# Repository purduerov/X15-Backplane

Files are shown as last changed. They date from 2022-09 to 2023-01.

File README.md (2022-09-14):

# Readme for X15-Backplane

Whenever you make a new part, download the datasheet and save it here _**and**_ with the part in the parts library

Always pull other people's changes before beginning to work
`git pull`

Be sure to push your changes after  working on them. Run:
1. `git add .` to add any files in this directory or a subdirectory
or `git add -u` to add any modified files
2. (Optional) `git clean -nX` to see what ignored files can be removed
	`git clean -fX` removes ignored files (Eagle backups)
3. `git commit -m "helpful commit message"` with a description of the work that you did
4. `git push` to push your work to github

Other helpful commands
* `git status` says information about modified and staged files
* `git log` shows the recent commits of the repository
* `git log filename.extension` show the recent commits for just that file
* `git checkout first-couple-letter-of-commit-id` lets you go back to a previous version
* `git checkout master` brings you back to the latest commit
* `git tag` lists the tags
* `git tag -a orderX -m "the version of the board placed for the X'th order"` tag a specific commit
* `git push --tags` needed to push tags to remote
* `git show orderX` show the commit log for the given tag
* `git checkout orderX` go back and interact with the files at the tagged commit

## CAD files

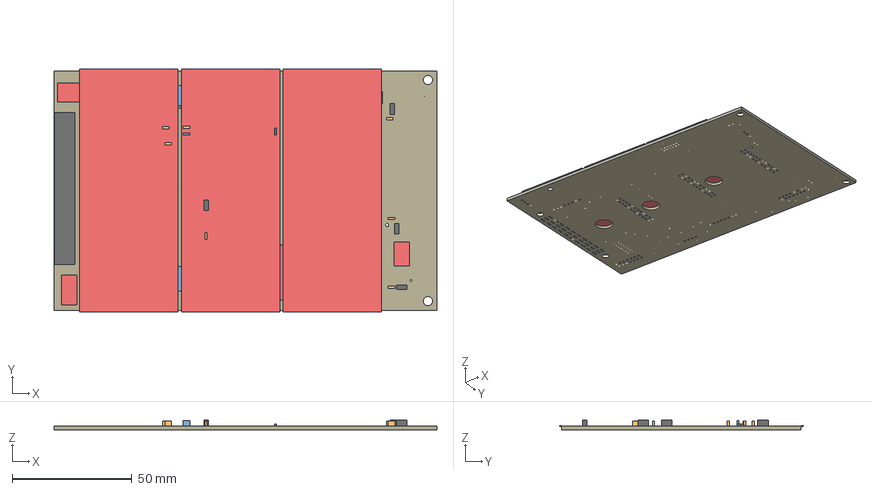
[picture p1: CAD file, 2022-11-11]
X15-Backplane.step
160.0 x 101.6 x 4.16 mm
Board
0.1uF
330uF x 8
PXC-PTSM-04-RA-1778641
0.5A/40V/420mV
MPPT-10-01-01-L-RA-SD
6-32-HOLE x 2
PXC-8-RA-1778683 x 2
BACKPLANE_ESC_ADAPTER_PWRBKP x 3
DISCRETECOMPONENTS_SW_2512
BACKPLANE-DISTRIBUTION
BACKPLANE->DATACONV
BACKPLANE_CONNECTORSBKP
LED_3MM x 4
8X_CONN
IPL1-103-01-L-S-K
IPL1-104-01-X-S-K

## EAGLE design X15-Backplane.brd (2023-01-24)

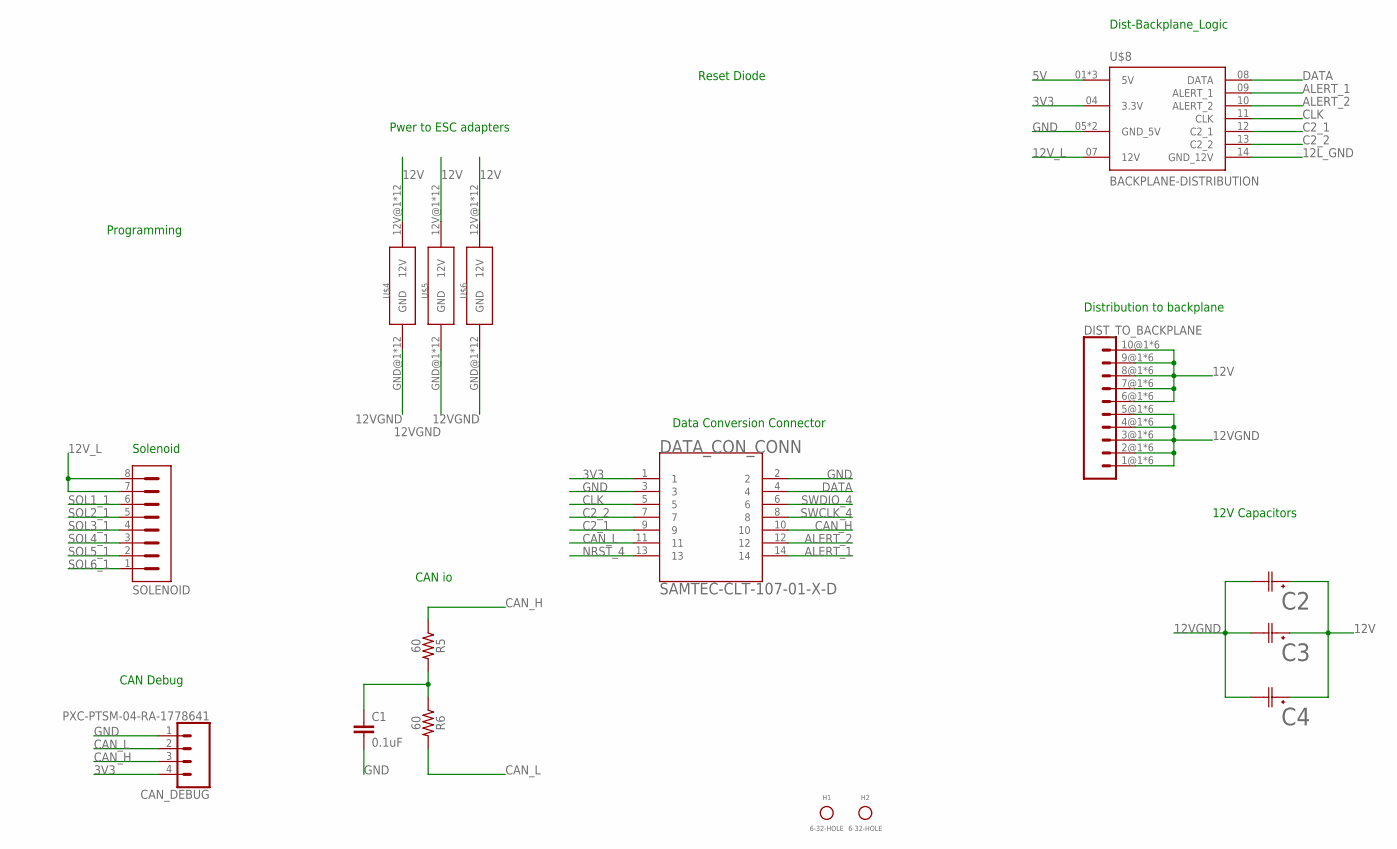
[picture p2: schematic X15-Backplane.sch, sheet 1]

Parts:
C1: 0.1uF; 0603
C2, C3, C4: UCV1E561MNL1GSCAP_UCD_8X10_NCH; CAP_UCD_8X10_NCH
CAN_DEBUG: PXC-PTSM-04-RA-1778641
DATA_CON_CONN: BACKPLANE->DATACONV; SAMTEC-CLT-107-01-X-D-BACKPLANE
DIST_TO_BACKPLANE: MPPT-10-01-01-L-RA-SD
H1, H2: 6-32-HOLE
R5, R6: 60; 0603
SOLENOID: PXC-8-RA-1778683
U$4, U$5, U$6: BACKPLANE_ESC_ADAPTER_PWRBKP; BACKPLANE_ESC_ADAPTER_BKP_PWR
U$8: BACKPLANE-DISTRIBUTION; SAMTEC_IPL1-107-01-X-D-K(B-D)

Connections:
3V3: CAN_DEBUG.4, DATA_CON_CONN.1, U$8.04 (3.3V); also elsewhere on the board
5V: U$8.01 (5V), U$8.02 (5V), U$8.03 (5V); also elsewhere on the board
12L_GND: U$8.14 (GND_12V); also elsewhere on the board
12V: C2.1, C3.1, C4.1, DIST_TO_BACKPLANE.6@1 (6), DIST_TO_BACKPLANE.6@2 (6), DIST_TO_BACKPLANE.6@3 (6), DIST_TO_BACKPLANE.6@4 (6), DIST_TO_BACKPLANE.6@5 (6), DIST_TO_BACKPLANE.6@6 (6), DIST_TO_BACKPLANE.7@1 (7), DIST_TO_BACKPLANE.7@2 (7), DIST_TO_BACKPLANE.7@3 (7), DIST_TO_BACKPLANE.7@4 (7), DIST_TO_BACKPLANE.7@5 (7), DIST_TO_BACKPLANE.7@6 (7), DIST_TO_BACKPLANE.8@1 (8), DIST_TO_BACKPLANE.8@2 (8), DIST_TO_BACKPLANE.8@3 (8), DIST_TO_BACKPLANE.8@4 (8), DIST_TO_BACKPLANE.8@5 (8), DIST_TO_BACKPLANE.8@6 (8), DIST_TO_BACKPLANE.9@1 (9), DIST_TO_BACKPLANE.9@2 (9), DIST_TO_BACKPLANE.9@3 (9), DIST_TO_BACKPLANE.9@4 (9), DIST_TO_BACKPLANE.9@5 (9), DIST_TO_BACKPLANE.9@6 (9), DIST_TO_BACKPLANE.10@1 (10), DIST_TO_BACKPLANE.10@2 (10), DIST_TO_BACKPLANE.10@3 (10), DIST_TO_BACKPLANE.10@4 (10), DIST_TO_BACKPLANE.10@5 (10), DIST_TO_BACKPLANE.10@6 (10), U$4.12V@1 (12V), U$4.12V@2 (12V), U$4.12V@3 (12V), U$4.12V@4 (12V), U$4.12V@5 (12V), U$4.12V@6 (12V), U$4.12V@7 (12V), U$4.12V@8 (12V), U$4.12V@9 (12V), U$4.12V@10 (12V), U$4.12V@11 (12V), U$4.12V@12 (12V), U$5.12V@1 (12V), U$5.12V@2 (12V), U$5.12V@3 (12V), U$5.12V@4 (12V), U$5.12V@5 (12V), U$5.12V@6 (12V), U$5.12V@7 (12V), U$5.12V@8 (12V), U$5.12V@9 (12V), U$5.12V@10 (12V), U$5.12V@11 (12V), U$5.12V@12 (12V), U$6.12V@1 (12V), U$6.12V@2 (12V), U$6.12V@3 (12V), U$6.12V@4 (12V), U$6.12V@5 (12V), U$6.12V@6 (12V), U$6.12V@7 (12V), U$6.12V@8 (12V), U$6.12V@9 (12V), U$6.12V@10 (12V), U$6.12V@11 (12V), U$6.12V@12 (12V); also elsewhere on the board
12VGND: C2.2, C3.2, C4.2, DIST_TO_BACKPLANE.1@1 (1), DIST_TO_BACKPLANE.1@2 (1), DIST_TO_BACKPLANE.1@3 (1), DIST_TO_BACKPLANE.1@4 (1), DIST_TO_BACKPLANE.1@5 (1), DIST_TO_BACKPLANE.1@6 (1), DIST_TO_BACKPLANE.2@1 (2), DIST_TO_BACKPLANE.2@2 (2), DIST_TO_BACKPLANE.2@3 (2), DIST_TO_BACKPLANE.2@4 (2), DIST_TO_BACKPLANE.2@5 (2), DIST_TO_BACKPLANE.2@6 (2), DIST_TO_BACKPLANE.3@1 (3), DIST_TO_BACKPLANE.3@2 (3), DIST_TO_BACKPLANE.3@3 (3), DIST_TO_BACKPLANE.3@4 (3), DIST_TO_BACKPLANE.3@5 (3), DIST_TO_BACKPLANE.3@6 (3), DIST_TO_BACKPLANE.4@1 (4), DIST_TO_BACKPLANE.4@2 (4), DIST_TO_BACKPLANE.4@3 (4), DIST_TO_BACKPLANE.4@4 (4), DIST_TO_BACKPLANE.4@5 (4), DIST_TO_BACKPLANE.4@6 (4), DIST_TO_BACKPLANE.5@1 (5), DIST_TO_BACKPLANE.5@2 (5), DIST_TO_BACKPLANE.5@3 (5), DIST_TO_BACKPLANE.5@4 (5), DIST_TO_BACKPLANE.5@5 (5), DIST_TO_BACKPLANE.5@6 (5), U$4.GND@1 (GND), U$4.GND@2 (GND), U$4.GND@3 (GND), U$4.GND@4 (GND), U$4.GND@5 (GND), U$4.GND@6 (GND), U$4.GND@7 (GND), U$4.GND@8 (GND), U$4.GND@9 (GND), U$4.GND@10 (GND), U$4.GND@11 (GND), U$4.GND@12 (GND), U$5.GND@1 (GND), U$5.GND@2 (GND), U$5.GND@3 (GND), U$5.GND@4 (GND), U$5.GND@5 (GND), U$5.GND@6 (GND), U$5.GND@7 (GND), U$5.GND@8 (GND), U$5.GND@9 (GND), U$5.GND@10 (GND), U$5.GND@11 (GND), U$5.GND@12 (GND), U$6.GND@1 (GND), U$6.GND@2 (GND), U$6.GND@3 (GND), U$6.GND@4 (GND), U$6.GND@5 (GND), U$6.GND@6 (GND), U$6.GND@7 (GND), U$6.GND@8 (GND), U$6.GND@9 (GND), U$6.GND@10 (GND), U$6.GND@11 (GND), U$6.GND@12 (GND)
12V_L: SOLENOID.7, SOLENOID.8, U$8.07 (12V); also elsewhere on the board
ALERT_1: DATA_CON_CONN.14, U$8.09 (ALERT_1)
ALERT_2: DATA_CON_CONN.12, U$8.10 (ALERT_2)
C2_1: DATA_CON_CONN.9, U$8.12 (C2_1)
C2_2: DATA_CON_CONN.7, U$8.13 (C2_2)
CAN_H: CAN_DEBUG.3, DATA_CON_CONN.10, R5.1; also elsewhere on the board
CAN_L: CAN_DEBUG.2, DATA_CON_CONN.11, R6.2; also elsewhere on the board
CLK: DATA_CON_CONN.5, U$8.11 (CLK)
DATA: DATA_CON_CONN.4, U$8.08 (DATA)
GND: C1.2, CAN_DEBUG.1, DATA_CON_CONN.2, DATA_CON_CONN.3, U$8.05 (GND_5V), U$8.06 (GND_5V); also elsewhere on the board
unnamed: C1.1, R5.2, R6.1
NRST_4: DATA_CON_CONN.13
SOL1_1: SOLENOID.6; also elsewhere on the board
SOL2_1: SOLENOID.5; also elsewhere on the board
SOL3_1: SOLENOID.4; also elsewhere on the board
SOL4_1: SOLENOID.3; also elsewhere on the board
SOL5_1: SOLENOID.2; also elsewhere on the board
SOL6_1: SOLENOID.1; also elsewhere on the board
SWCLK_4: DATA_CON_CONN.8
SWDIO_4: DATA_CON_CONN.6

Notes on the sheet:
Programming
Distribution to backplane
Dist-Backplane_Logic
Pwer to ESC adapters
Reset Diode
Solenoid
12V Capacitors
CAN io
CAN Debug
Data Conversion Connector

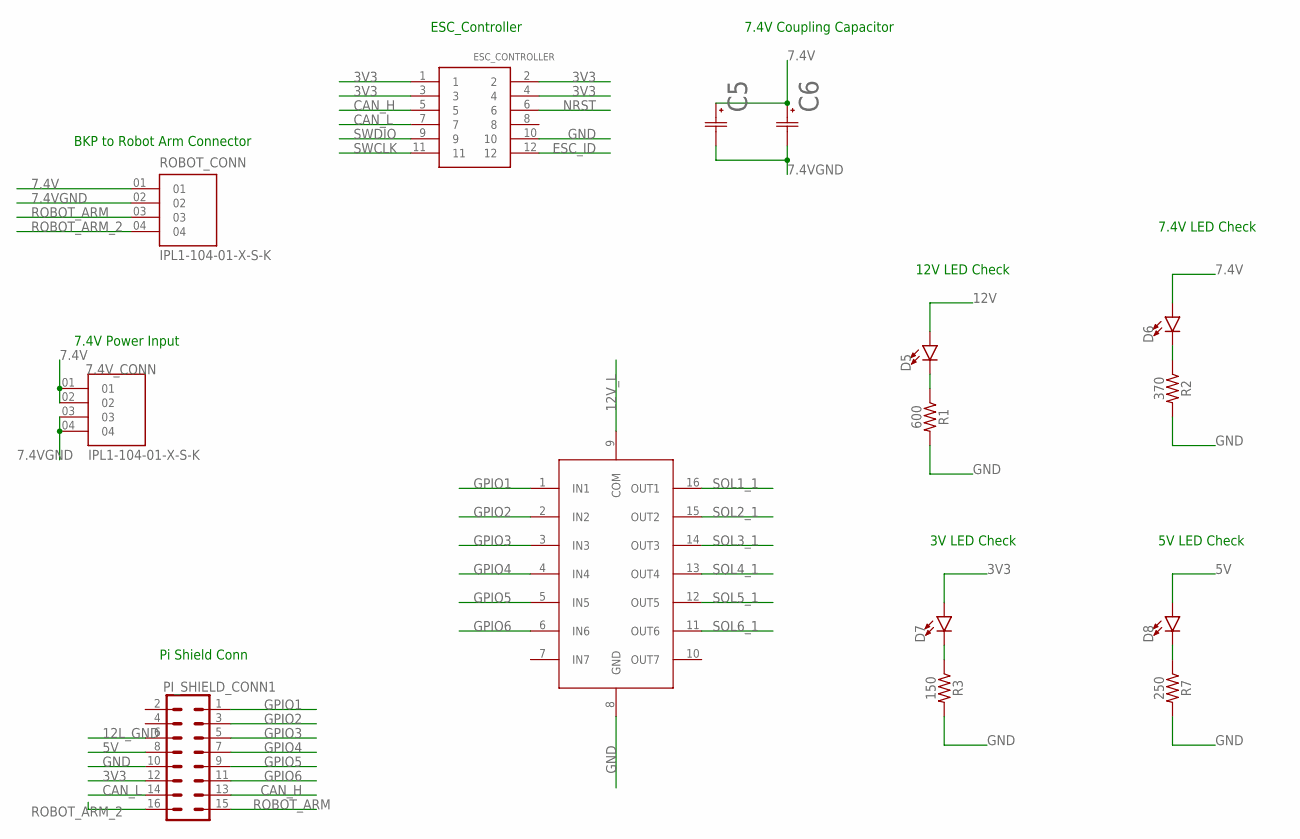
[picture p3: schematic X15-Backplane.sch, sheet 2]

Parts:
7.4V_CONN: IPL1-104-01-X-S-K; SAMTEC_IPL1-104-01-X-S-K
C5, C6: UCV1E561MNL1GSCAP_UCD_8X10_NCH; CAP_UCD_8X10_NCH
D5, D6, D7, D8: LED0603; LED-0603
ESC_CONTROLLER: BACKPLANE_CONNECTORSBKP; BACKPLANE_CONNECTORS_BKP
PI_SHIELD_CONN1: 8X_CONN; IPL7X2
R1: 600; 0603
R2: 370; 0603
R3: 150; 0603
R7: 250; 0603
ROBOT_CONN: IPL1-104-01-X-S-K; SAMTEC_IPL1-104-01-X-S-K
U1: ULN2003AD; 16-SOIC

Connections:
3V3: D7.A, ESC_CONTROLLER.1, ESC_CONTROLLER.2, ESC_CONTROLLER.3, ESC_CONTROLLER.4, PI_SHIELD_CONN1.12 (23); also elsewhere on the board
5V: D8.A, PI_SHIELD_CONN1.8 (19); also elsewhere on the board
7.4V: 7.4V_CONN.01, 7.4V_CONN.02, C5.1, C6.1, D6.A, ROBOT_CONN.01
7.4VGND: 7.4V_CONN.03, 7.4V_CONN.04, C5.2, C6.2, ROBOT_CONN.02
12L_GND: PI_SHIELD_CONN1.6 (17); also elsewhere on the board
12V: D5.A; also elsewhere on the board
12V_L: U1.9 (COM); also elsewhere on the board
CAN_H: ESC_CONTROLLER.5, PI_SHIELD_CONN1.13 (1); also elsewhere on the board
CAN_L: ESC_CONTROLLER.7, PI_SHIELD_CONN1.14 (2); also elsewhere on the board
ESC_ID: ESC_CONTROLLER.12
GND: ESC_CONTROLLER.10, PI_SHIELD_CONN1.10 (21), R1.2, R2.2, R3.2, R7.2, U1.8 (GND); also elsewhere on the board
GPIO1: PI_SHIELD_CONN1.1 (14), U1.1 (IN1)
GPIO2: PI_SHIELD_CONN1.3 (16), U1.2 (IN2)
GPIO3: PI_SHIELD_CONN1.5 (18), U1.3 (IN3)
GPIO4: PI_SHIELD_CONN1.7 (20), U1.4 (IN4)
GPIO5: PI_SHIELD_CONN1.9 (22), U1.5 (IN5)
GPIO6: PI_SHIELD_CONN1.11 (24), U1.6 (IN6)
unnamed: D6.C, R2.1
unnamed: D5.C, R1.1
unnamed: D7.C, R3.1
unnamed: D8.C, R7.1
NRST: ESC_CONTROLLER.6
ROBOT_ARM: PI_SHIELD_CONN1.15 (4), ROBOT_CONN.03
ROBOT_ARM_2: PI_SHIELD_CONN1.16 (3), ROBOT_CONN.04
SOL1_1: U1.16 (OUT1); also elsewhere on the board
SOL2_1: U1.15 (OUT2); also elsewhere on the board
SOL3_1: U1.14 (OUT3); also elsewhere on the board
SOL4_1: U1.13 (OUT4); also elsewhere on the board
SOL5_1: U1.12 (OUT5); also elsewhere on the board
SOL6_1: U1.11 (OUT6); also elsewhere on the board
SWCLK: ESC_CONTROLLER.11
SWDIO: ESC_CONTROLLER.9

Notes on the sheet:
ESC_Controller
7.4V LED Check
7.4V Coupling Capacitor
Pi Shield Conn
BKP to Robot Arm Connector
7.4V Power Input
12V LED Check
3V LED Check
5V LED Check

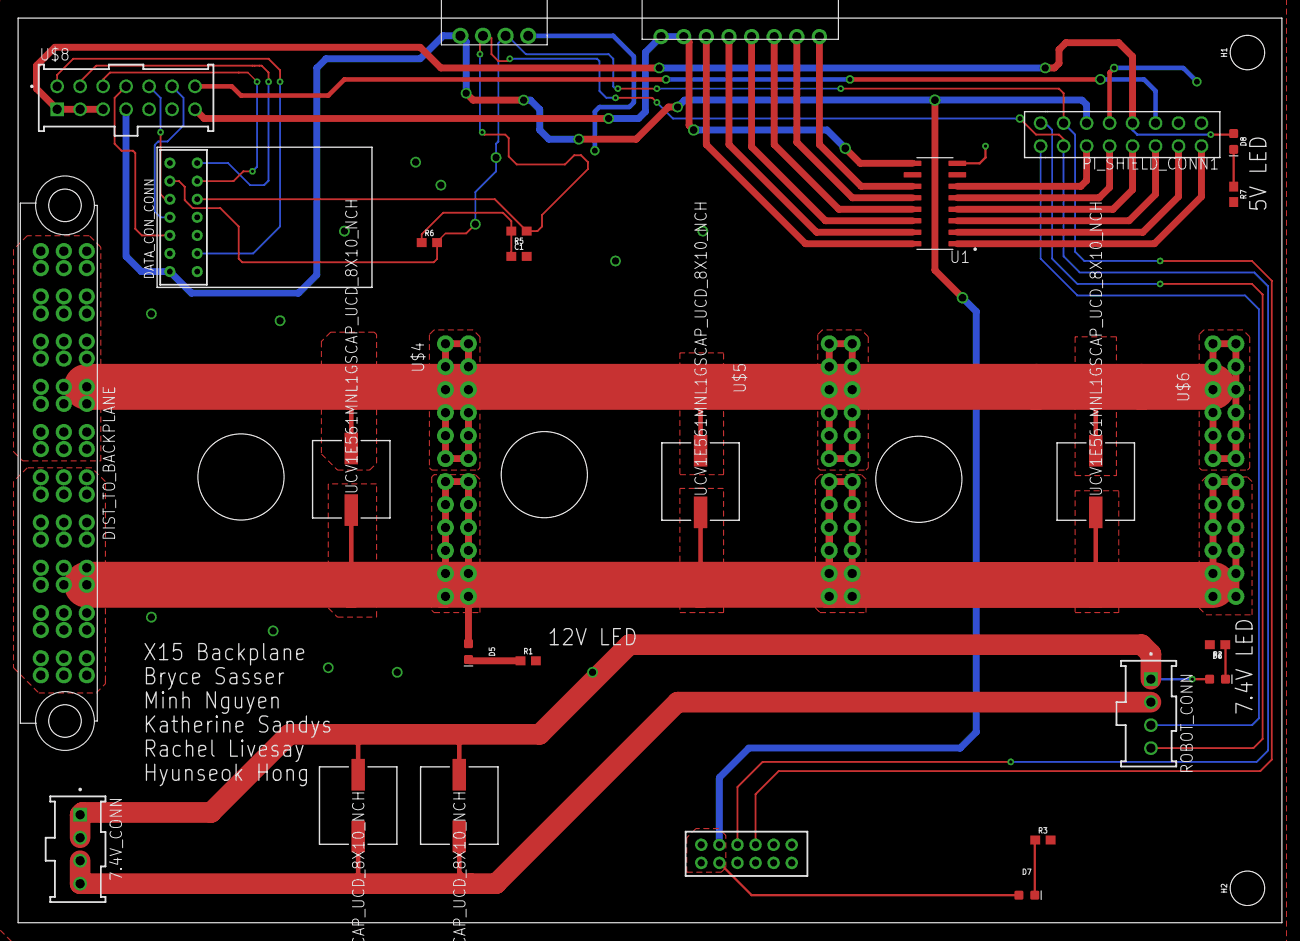
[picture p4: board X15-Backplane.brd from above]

Board: 2 copper layers, 139.7 x 100.0 mm, 31 parts (0 on the bottom side), 36 nets.

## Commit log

2022-10-15 Sorry for not pushing regularly
    [X15-Backplane.sch]
2022-10-22 Two Sheets
    [X15-Backplane.sch]
2022-10-22 Library Fixed
    [X15-Backplane.sch]
2022-10-22 LED Added
    [X15-Backplane.sch]
2022-10-22 board dimensions
    [X15-Backplane.brd]
2022-11-11 Minor chnages to clean up some traces
    [X15-Backplane.brd]
2022-11-11 12V Wire Fixed
    [X15-Backplane.brd]
2022-12-08 clearance fixed
    [X15-Backplane.brd]
2022-12-22 fixed dimensions
    [X15-Backplane.brd]
2023-01-03 Capacitor Changed
    [X15-Backplane.brd, X15-Backplane.sch]
2023-01-12 Polygon finished
    [X15-Backplane.brd]
2023-01-24 ESC Fixed
    [X15-Backplane.brd]

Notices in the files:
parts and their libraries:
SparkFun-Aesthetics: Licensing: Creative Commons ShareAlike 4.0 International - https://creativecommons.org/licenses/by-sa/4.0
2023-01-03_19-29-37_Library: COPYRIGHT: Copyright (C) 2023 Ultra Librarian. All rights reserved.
